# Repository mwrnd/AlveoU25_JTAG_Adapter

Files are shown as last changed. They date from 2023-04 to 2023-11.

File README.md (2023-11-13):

**Work-In-Progress** : [Design manufactured and works](https://github.com/mwrnd/AlveoU25_JTAG_Adapter/releases/download/v0.2-alpha/AlveoU25_JTAG_Adapter_Gerbers.zip) but a footprint is incorrect.

# AlveoU25_JTAG_Adapter

Alveo U25 Debug Connector to Xilinx JTAG, UART, and I2C.

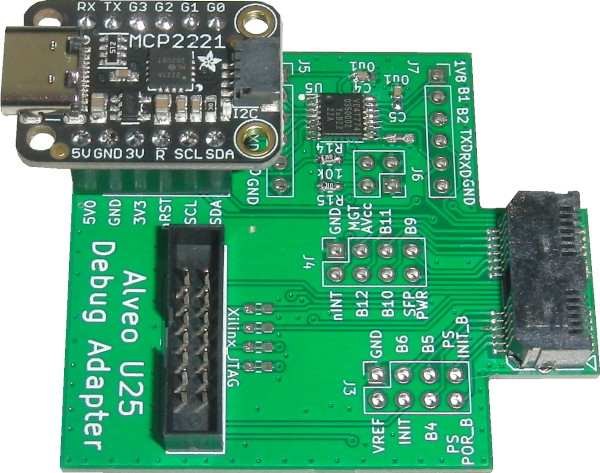
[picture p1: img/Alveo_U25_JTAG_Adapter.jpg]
Alveo U25 JTAG Adapter


The Adafruit 4471 footprint I used is off by 0.1". Its headers had to be soldered at an angle to work.

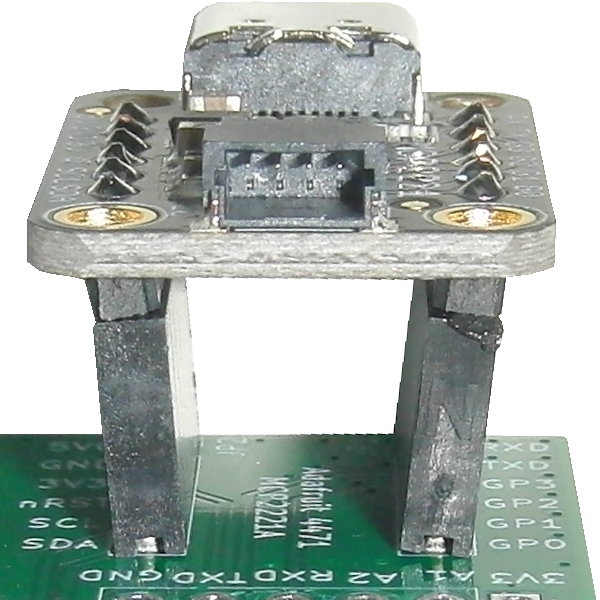
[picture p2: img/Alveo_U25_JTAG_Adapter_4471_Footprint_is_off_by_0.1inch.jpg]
Footprint is Incorrect


I have successfully used it to debug and program an Alveo U25.

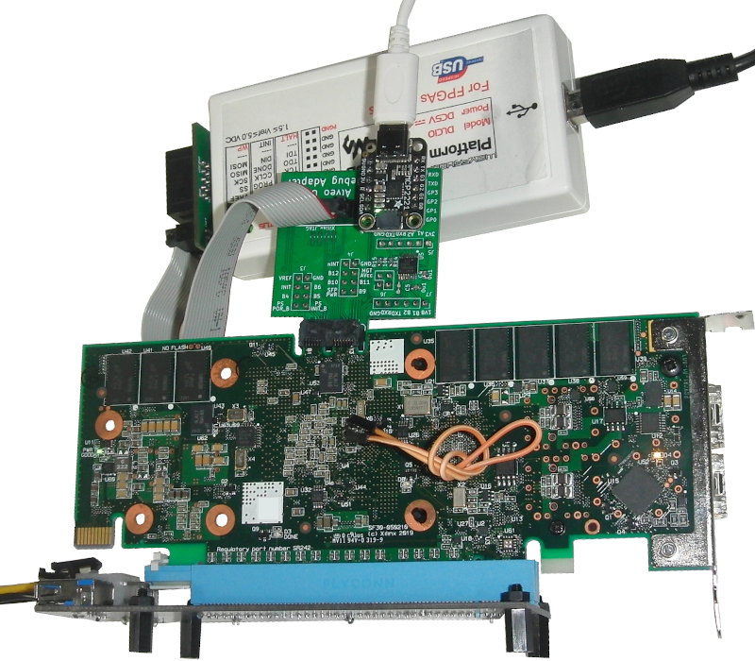
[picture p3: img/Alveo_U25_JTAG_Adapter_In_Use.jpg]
Alveo U25 JTAG Adapter in Use


The pinout is not available publicly so the signals had to be [traced out](https://github.com/mwrnd/alveo_u25_notes/blob/main/debug_log.md#figuring-out-the-jtag-debug-connector).

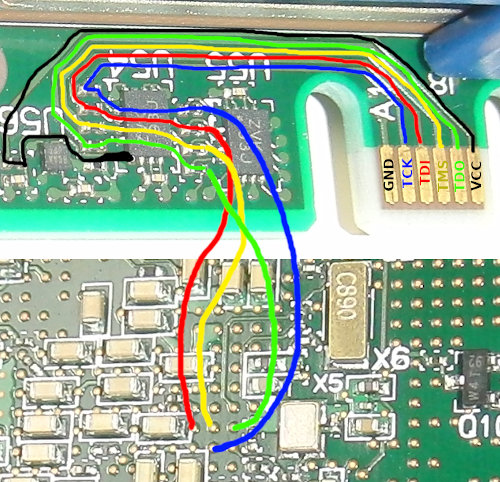
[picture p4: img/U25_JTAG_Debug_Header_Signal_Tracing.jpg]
Tracing Alveo U25 JTAG Signals


## Schematic

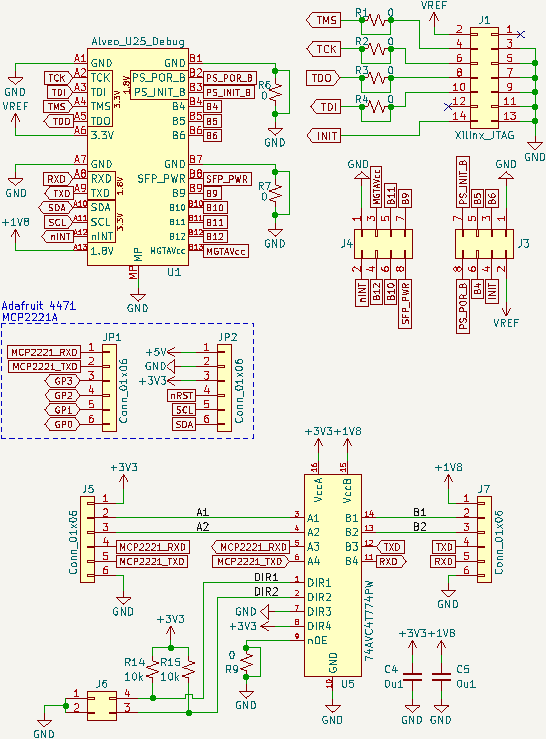
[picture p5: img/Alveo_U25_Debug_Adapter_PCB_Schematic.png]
Schematic


## PCB Layout

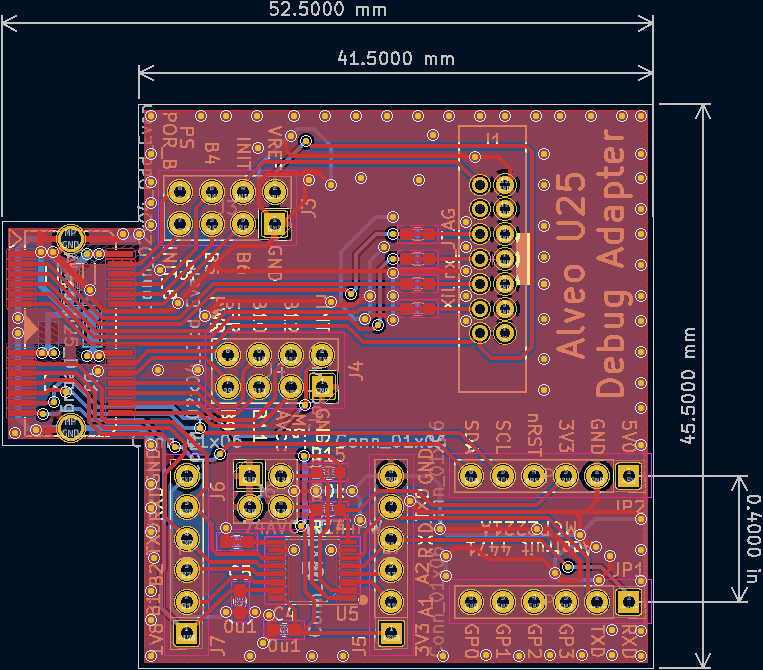
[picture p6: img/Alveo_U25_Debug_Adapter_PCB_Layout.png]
PCB Layout


## Bill Of Materials

**Necessary:**

| Designator(s) | Part Number | Quantity | Footprint | Availability |
| --- | --- | --- | --- | --- |
| U1 | MEC8-113-02-L-D-RA1  | 1 | MEC8-113-02-L-D | [TrustedParts](https://www.trustedparts.com/en/search/MEC8-113-02-L-D-RA1)  |
| J1 | SBH21-NBPN-D07-ST-BK | 1 | SBH21-NBPN-D07-ST | [TrustedParts](https://www.trustedparts.com/en/search/SBH21-NBPN-D07-ST-BK) |
| U5 | 74AVC4T774PW | 1 | TSSOP-16 | [TrustedParts](https://www.trustedparts.com/en/search/74AVC4T774PW) |
| R14, R15 | RNCP0603FTD10K0 | 2 | 0603 | [TrustedParts](https://www.trustedparts.com/en/search/RNCP0603FTD10K0) |
| C4, C5 | CL10B104JB8NNNC | 2 | 0603 | [TrustedParts](https://www.trustedparts.com/en/search/CL10B104JB8NNNC) |
| JP1, JP2 | PPTC061LFBN-RC | 2 | 1x06_2.54mm | [TrustedParts](https://www.trustedparts.com/en/search/PPTC061LFBN-RC) |
| x | Adafruit 4471 | 1 | None - Module | [TrustedParts](https://www.trustedparts.com/en/part/adafruit/4471) |

**Optional:**

| Designator(s) | Part Number | Quantity | Footprint | Availability |
| --- | --- | --- | --- | --- |
| J5, J7 | PPTC061LFBN-RC | 2 | 1x06_2.54mm | [TrustedParts](https://www.trustedparts.com/en/search/PPTC061LFBN-RC) |
| J3, J4 | PPTC042LFBN-RC | 2 | 2x04_2.54x2.54mm  | [TrustedParts](https://www.trustedparts.com/en/search/PPTC042LFBN-RC) |
| J6 | PREC002DAAN-RC | 1 | 2x02_2.54mm | [TrustedParts](https://www.trustedparts.com/en/search/PREC002DAAN-RC) |
| x, x | STC02SYAN | | None - Jumper | [TrustedParts](https://www.trustedparts.com/en/search/STC02SYAN) |

## Previous Version

[`v0.1-alpha`](https://github.com/mwrnd/AlveoU25_JTAG_Adapter/releases/tag/v0.1-alpha) was a basic breakout board for the Alveo U25 Debug Connector. It was never manufactured or tested.

Only two components would have been required: [MEC8-113-02-L-D-RA1](https://www.trustedparts.com/en/search/MEC8-113-02-L-D-RA1) and [SBH21-NBPN-D07-ST-BK](https://www.trustedparts.com/en/search/SBH21-NBPN-D07-ST-BK).

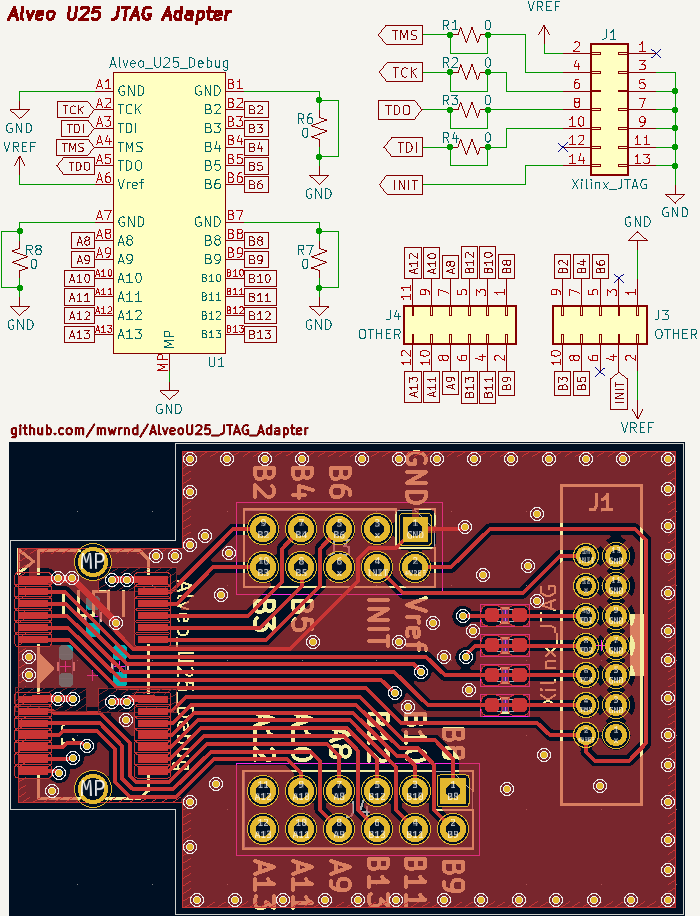
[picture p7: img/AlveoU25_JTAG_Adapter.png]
Alveo U25 to Xilinx JTAG Adapter


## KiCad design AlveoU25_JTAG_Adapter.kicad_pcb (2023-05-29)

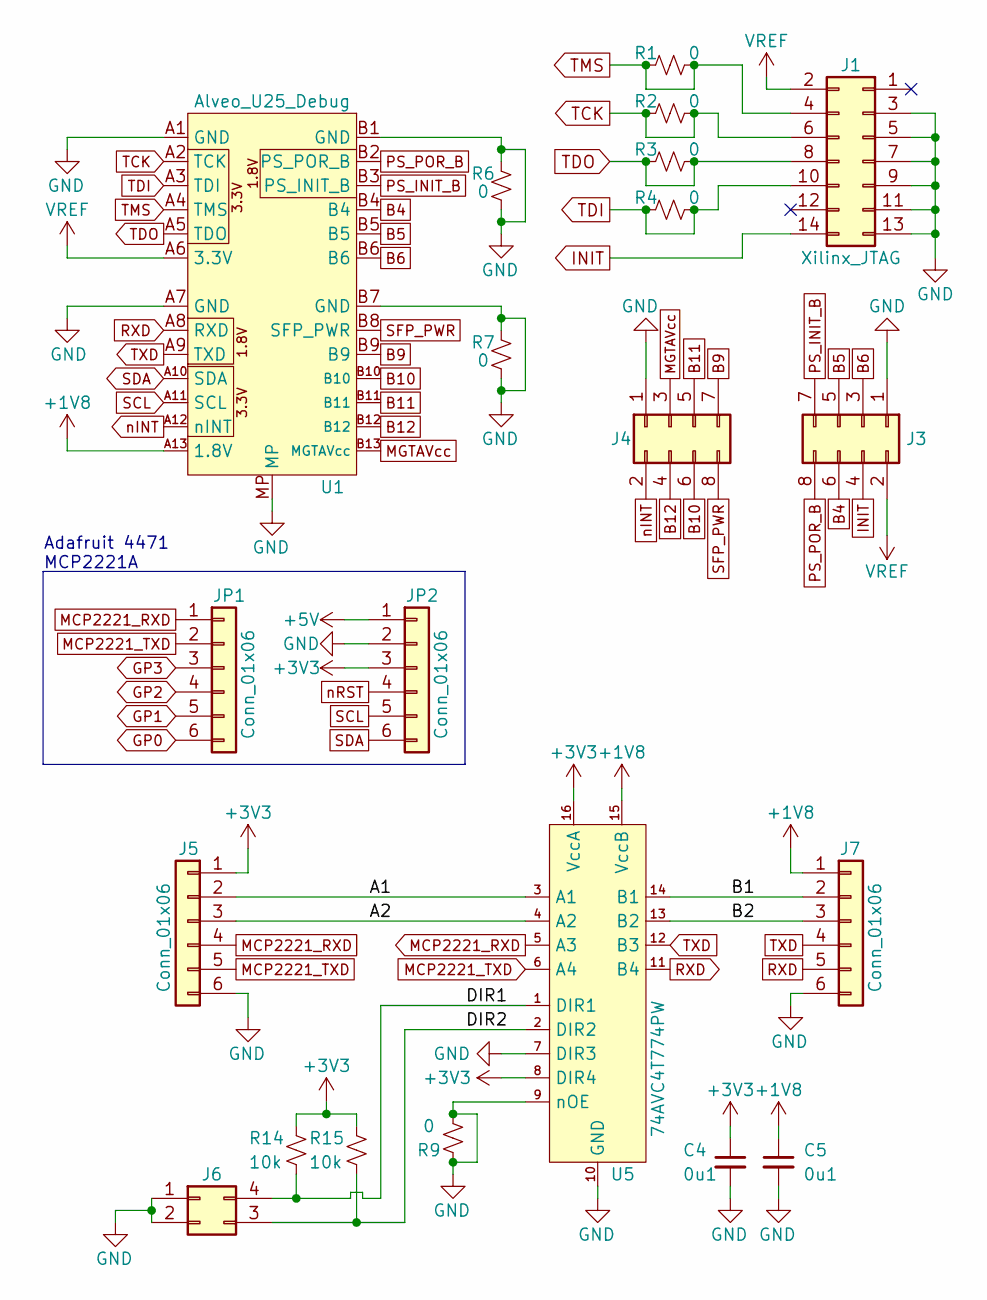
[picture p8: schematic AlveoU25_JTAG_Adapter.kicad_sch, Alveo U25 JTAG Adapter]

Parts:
C4, C5: 0u1; C_0603_1608Metric_Pad1.08x0.95mm_HandSolder
J1: Xilinx_JTAG; SBH21-NBPN-D07-ST
J3, J4: Conn_02x04_Odd_Even; PinSocket_2x04_P2.54mm_Vertical
J5, J7: Conn_01x06; PinSocket_1x06_P2.54mm_Vertical
J6: Conn_02x02_Counter_Clockwise; PinSocket_2x02_P2.54mm_Vertical
JP1, JP2: Conn_01x06; PinSocket_1x06_P2.54mm_Vertical
R1, R2, R3, R4, R6, R7, R9: 0; R_0603_1608Metric_Pad0.98x0.95mm_HandSolder
R14, R15: 10k; R_0603_1608Metric_Pad0.98x0.95mm_HandSolder
U1: Alveo_U25_Debug; MEC8-113-02-L-D-RA1
U5: 74AVC4T774PW; TSSOP-16_4.4x5mm_P0.65mm

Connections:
+1V8: C5.1, J7.1, U1.A13 (1.8V), U5.15 (VccB)
+3V3: C4.1, J5.1, JP2.3, R14.1, R15.1, U5.8 (DIR4), U5.16 (VccA)
+5V: JP2.1
+VREF: J1.2, J3.2, U1.A6 (3.3V)
/A1: J5.2, U5.3 (A1)
/A2: J5.3, U5.4 (A2)
/B1: J7.2, U5.14 (B1)
/B2: J7.3, U5.13 (B2)
/DIR1: J6.4, R14.2, U5.1 (DIR1)
/DIR2: J6.3, R15.2, U5.2 (DIR2)
B4: J3.6, U1.B4
B5: J3.5, U1.B5
B6: J3.3, U1.B6
B9: J4.7, U1.B9
B10: J4.6, U1.B10
B11: J4.5, U1.B11
B12: J4.4, U1.B12
GND: C4.2, C5.2, J1.3, J1.5, J1.7, J1.9, J1.11, J1.13, J3.1, J4.1, J5.6, J6.1, J6.2, J7.6, JP2.2, R6.1, R6.2, R7.1, R7.2, R9.1, R9.2, U1.A1 (GND), U1.A7 (GND), U1.B1 (GND), U1.B7 (GND), U1.MP, U5.7 (DIR3), U5.9 (nOE), U5.10 (GND)
GP0: JP1.6
GP1: JP1.5
GP2: JP1.4
GP3: JP1.3
INIT: J1.14, J3.4
MCP2221_RXD: J5.4, JP1.1, U5.5 (A3)
MCP2221_TXD: J5.5, JP1.2, U5.6 (A4)
MGTAVcc: J4.3, U1.B13 (MGTAVcc)
PS_INIT_B: J3.7, U1.B3 (PS_INIT_B)
PS_POR_B: J3.8, U1.B2 (PS_POR_B)
RXD: J7.5, U1.A8 (RXD), U5.11 (B4)
SCL: JP2.5, U1.A11 (SCL)
SDA: JP2.6, U1.A10 (SDA)
SFP_PWR: J4.8, U1.B8 (SFP_PWR)
TCK: J1.6, R2.1, R2.2, U1.A2 (TCK)
TDI: J1.10, R4.1, R4.2, U1.A3 (TDI)
TDO: J1.8, R3.1, R3.2, U1.A5 (TDO)
TMS: J1.4, R1.1, R1.2, U1.A4 (TMS)
TXD: J7.4, U1.A9 (TXD), U5.12 (B3)
nINT: J4.2, U1.A12 (nINT)
nRST: JP2.4

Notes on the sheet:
Adafruit 4471 MCP2221A

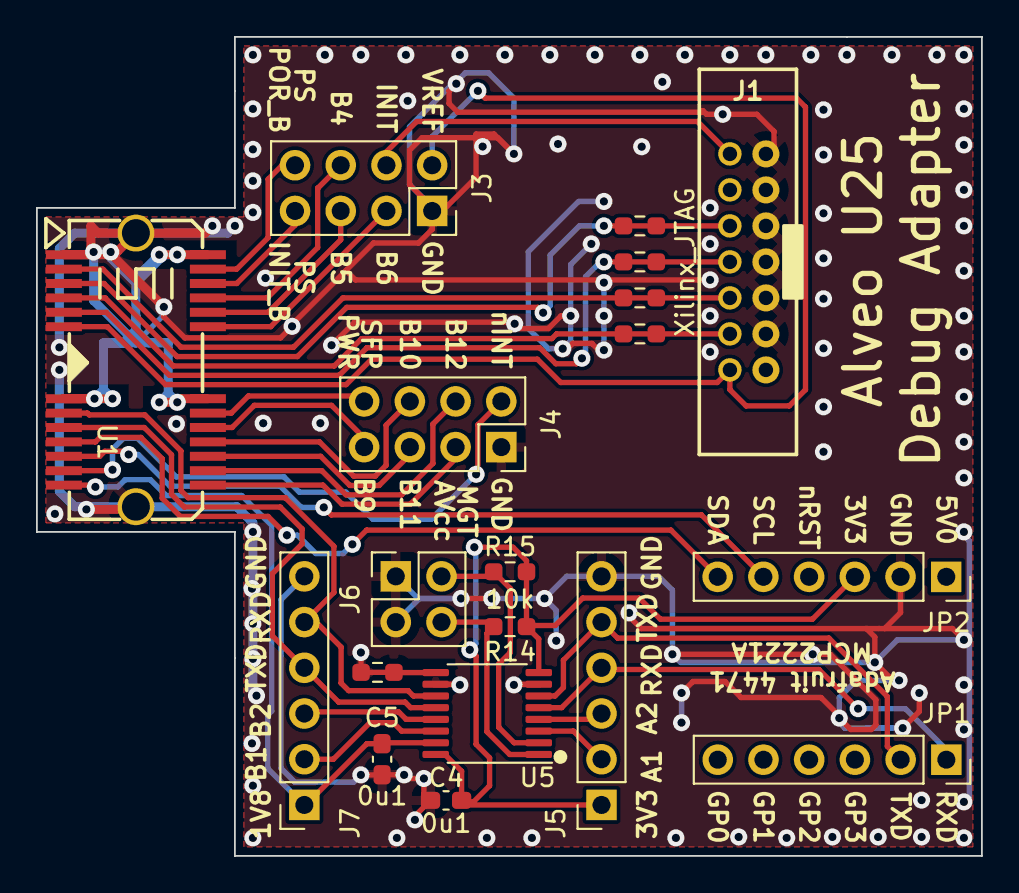
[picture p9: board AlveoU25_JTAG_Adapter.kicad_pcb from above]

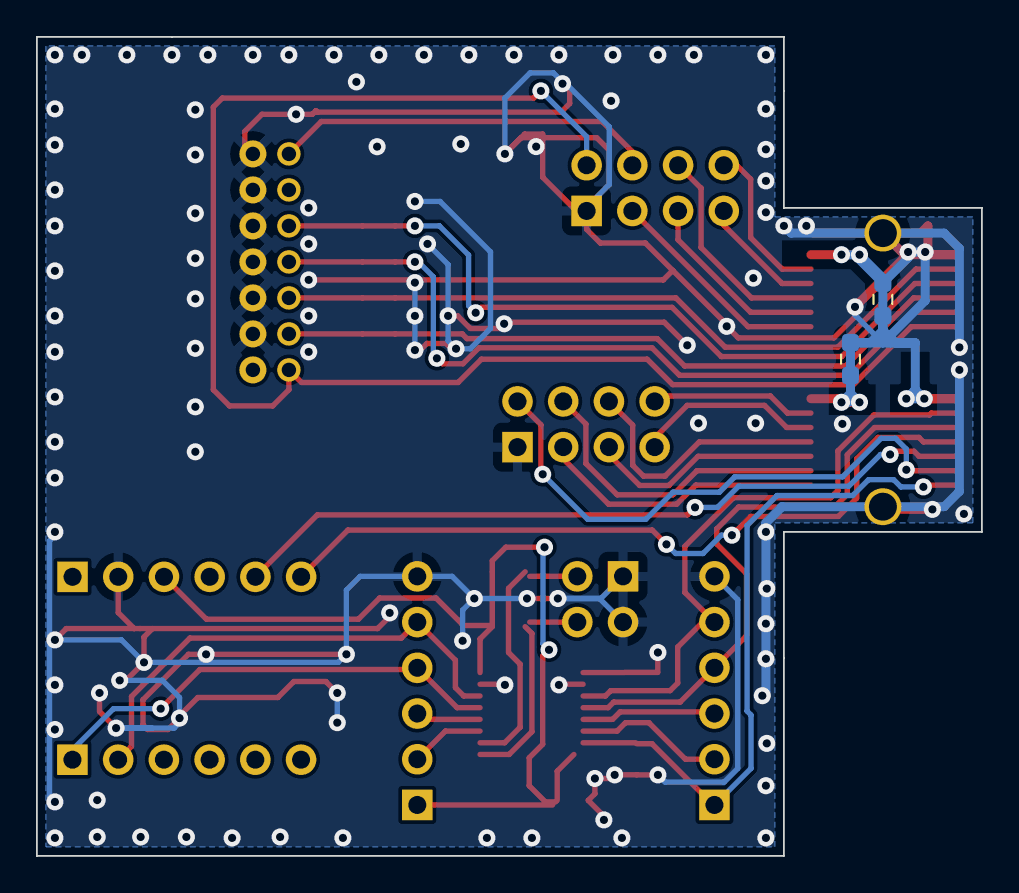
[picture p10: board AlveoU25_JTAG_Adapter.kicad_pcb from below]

Board: 2 copper layers, 52.5 x 45.5 mm, 21 parts (2 on the bottom side), 33 nets.

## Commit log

2023-03-16 Symbols and Footprints Finished
    [AlveoU25_JTAG_Adapter.kicad_pcb, AlveoU25_JTAG_Adapter.kicad_sch]
2023-04-04 PCB Finished - Just JTAG
    [AlveoU25_JTAG_Adapter.kicad_pcb, AlveoU25_JTAG_Adapter.kicad_sch]
2023-05-29 Second Revision
    [AlveoU25_JTAG_Adapter.kicad_pcb, AlveoU25_JTAG_Adapter.kicad_sch]
